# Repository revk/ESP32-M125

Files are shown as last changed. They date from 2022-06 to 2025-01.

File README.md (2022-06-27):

# ESP32-M125

This is hardware and software designed to be fitted within a Marsden M-125 set of medical scales.

Examples of modifications with much older prototype boards https://youtu.be/l1VAymhwtVMand  https://youtu.be/jy-5EB_Qu8Y

M125 09 51 44

Takes data when SEND pressed and reports via MQTT and https. But can also work with an NFC board https://github.com/revk/ESP32-PN532 so tapping a card or tag will report ID and weight, pressing SEND for you.

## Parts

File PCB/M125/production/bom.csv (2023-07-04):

Designator | Footprint | Quantity | Value | LCSC Part #
C1 | C_0402 | 1 | 1uF
C2 | C_0402 | 1 | 100nF
C6 | C_0603_ | 1 | 10uF 50V | C1591
C7 | C_0603_ | 1 | 10uF 6.3V | C1691
C8 | C_0603_ | 1 | 100nF
D3 | LED-RGB-1.6x1.6 | 1 | RGB | C264508
J1, J2 | PTSM-HH-4-RA | 2 | Conn_01x04
J3 | Shelly | 1 | Shelly
L2 | L_4x4_ | 1 | 10uH
Q1 | SOT-323_SC-70 | 1 | PMF250XNEX
R10 | R_0402_ | 1 | 124k
R11 | R_0402_ | 1 | 39k2
R12 | R_0402_ | 1 | 1M
R4 | R_0402 | 1 | 10K
R7 | R_0402 | 1 | 680R
R8 | R_0402 | 1 | 2K
R9 | R_0402 | 1 | 220R
U1 | ESP32-PICO-MINI-02 | 1 | ESP32-PICO-MINI-02
U3 | SOT-23-6-MD8942 | 1 | MD8942 | C2684786

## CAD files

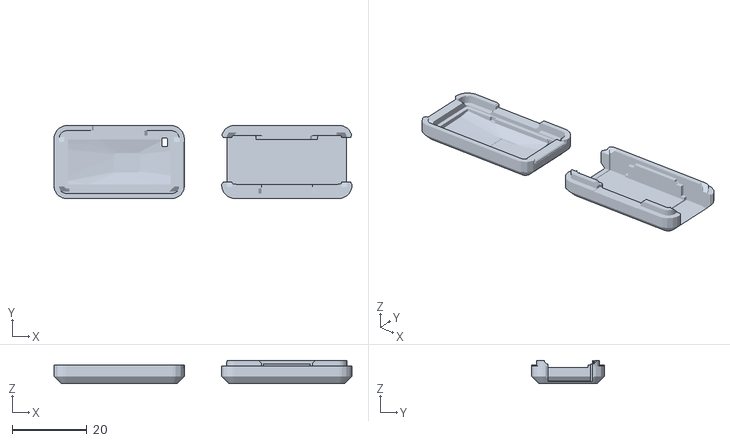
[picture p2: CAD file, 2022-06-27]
PCB/M125/M125.stl
80.0 x 19.6 x 6.30

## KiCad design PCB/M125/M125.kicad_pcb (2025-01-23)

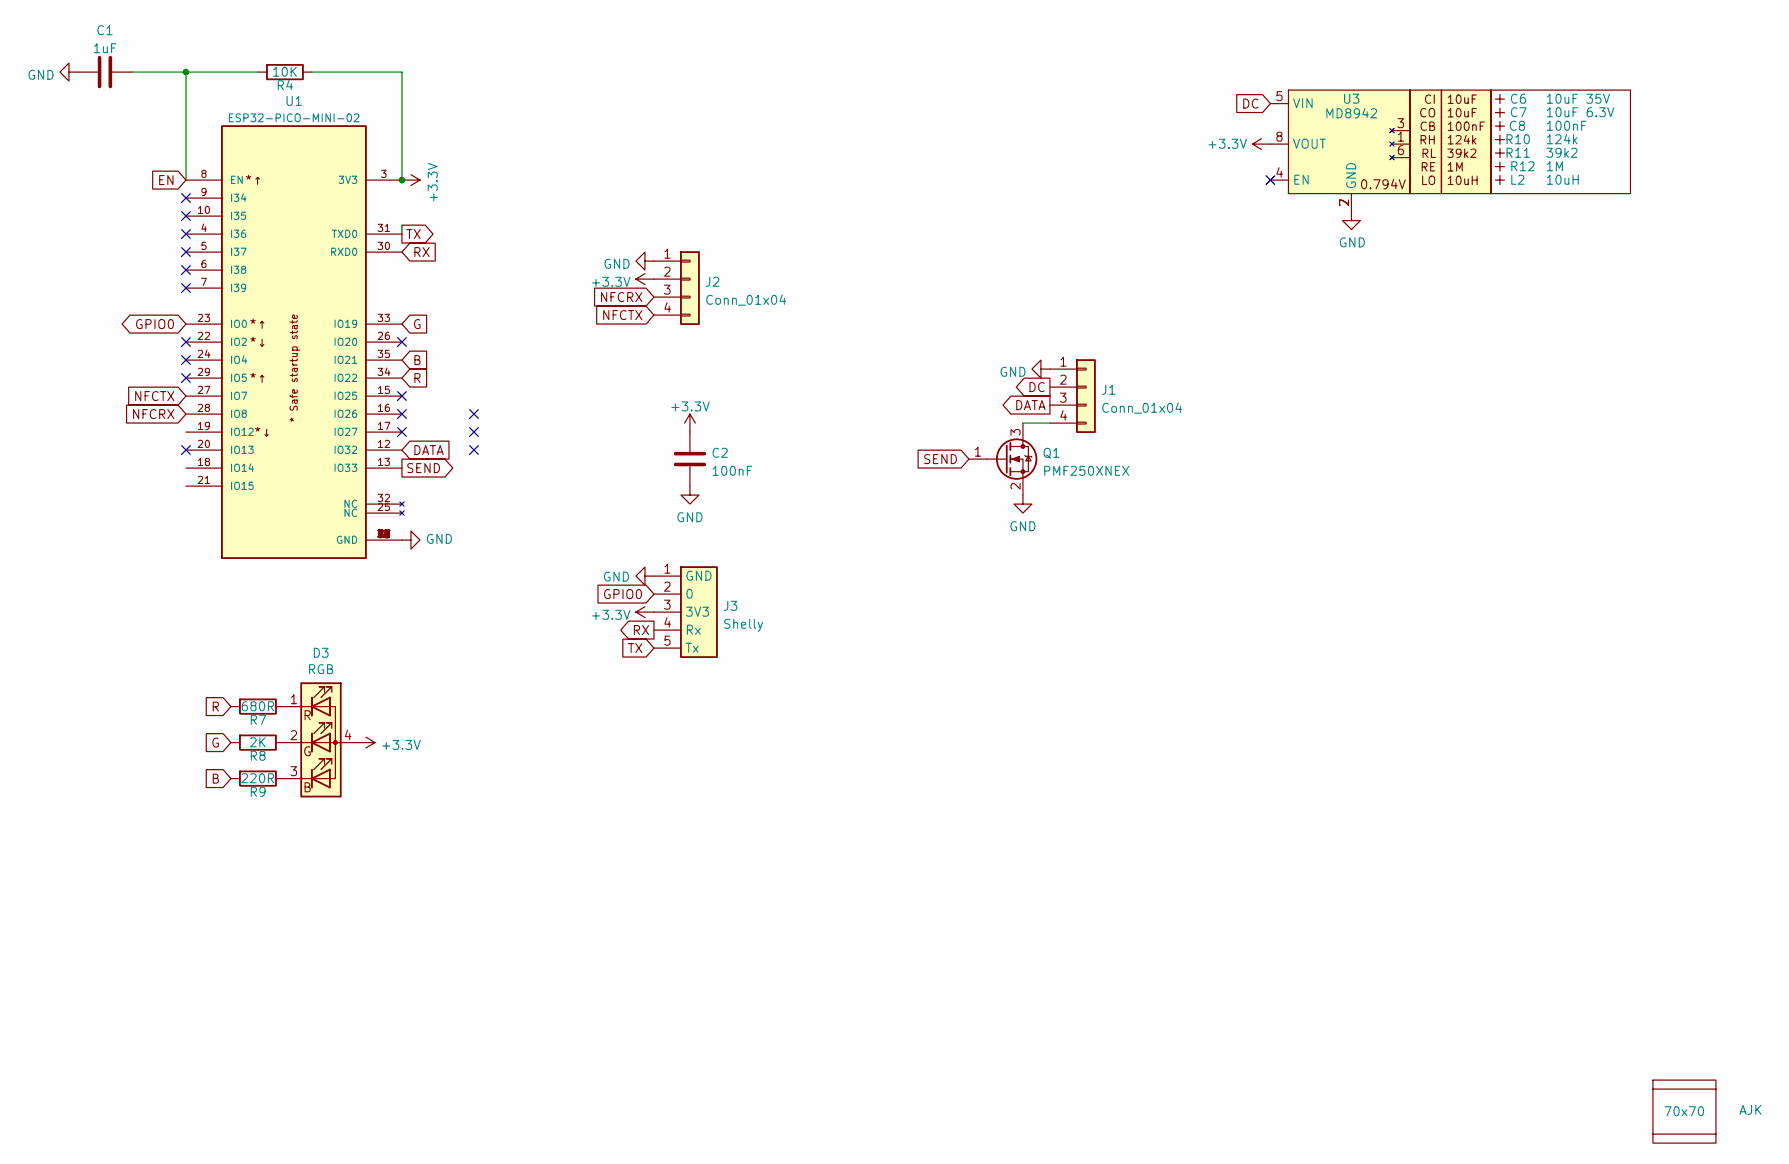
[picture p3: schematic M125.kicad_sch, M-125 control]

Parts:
C1: 1uF; C_0402
C2: 100nF; C_0402
C6: 10uF 35V; C_0603_; MPN C194427
C7: 10uF 6.3V; C_0603_; MPN C1691
C8: 100nF; C_0603_
D3: RGB; LED-RGB-1.6x1.6; Part No APTF1616LSEEZGKQBKC
J1, J2: Conn_01x04; PTSM-HH-4-RA
J3: Shelly
L2: 10uH; L_4x4_
Logo1: AJK
PCB1: 70x70; PCB7070
Q1: PMF250XNEX; SOT-323_SC-70; Part No PMF250XNEX
R4: 10K; R_0402
R7: 680R; R_0402
R8: 2K; R_0402
R9: 220R; R_0402
R10: 124k; R_0402_
R11: 39k2; R_0402_
R12: 1M; R_0402_
U1: ESP32-PICO-MINI-02; PARTREV v1.0
U3: MD8942; SOT-23-6-MD8942; MPN C2684786
V1, V2: VCUT70

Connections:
+3V3: C2.1, D3.4 (A), J2.2, J3.3 (3V3), R4.1, U1.3 (3V3), U3.8 (VOUT)
B: R9.2, U1.35 (IO21)
DATA: J1.3, U1.12 (IO32)
DC: J1.2, U3.5 (VIN)
EN: C1.2, R4.2, U1.8 (EN)
G: R8.2, U1.33 (IO19)
GND: C1.1, C2.2, J1.1, J2.1, J3.1 (GND), Q1.2 (S), U1.1 (GND), U1.2 (GND), U1.11 (GND), U1.14 (GND), U1.36 (GND), U1.37 (GND), U1.38 (GND), U1.39 (GND), U1.40 (GND), U1.41 (GND), U1.42 (GND), U1.43 (GND), U1.44 (GND), U1.45 (GND), U1.46 (GND), U1.47 (GND), U1.48 (GND), U1.49 (GND), U1.50 (GND), U1.51 (GND), U1.52 (GND), U1.53 (GND), U3.2 (GND), U3.7 (GND)
GPIO0: J3.2 (0), U1.23 (IO0)
NFCRX: J2.3, U1.28 (IO8)
NFCTX: J2.4, U1.27 (IO7)
unnamed: D3.3 (BK), R9.1
unnamed: D3.2 (GK), R8.1
unnamed: D3.1 (RK), R7.1
unnamed: J1.4, Q1.3 (D)
R: R7.2, U1.34 (IO22)
RX: J3.4 (Rx), U1.30 (RXD0)
SEND: Q1.1 (G), U1.13 (IO33)
TX: J3.5 (Tx), U1.31 (TXD0)

Board: 2 copper layers, 24 parts (18 on the bottom side), 18 nets, no tracks yet.

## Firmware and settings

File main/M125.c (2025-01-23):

/* M125 app */
/* Copyright ©2022 Adrian Kennard, Andrews & Arnold Ltd.See LICENCE file for details .GPL 3.0 */

static const char __attribute__((unused)) TAG[] = "M125";

#include "revk.h"
#include "esp_sleep.h"
#include "esp_task_wdt.h"
#include "esp_http_client.h"
#include "esp_http_server.h"
#include "esp_crt_bundle.h"
#include "pn532.h"
#include <driver/gpio.h>
#include <driver/uart.h>

#ifdef	CONFIG_LWIP_DHCP_DOES_ARP_CHECK
#warning CONFIG_LWIP_DHCP_DOES_ARP_CHECK means DHCP is slow
#endif
#ifndef	CONFIG_LWIP_DHCP_RESTORE_LAST_IP
#warning CONFIG_LWIP_DHCP_RESTORE_LAST_IP may improve speed
#endif
#ifndef	CONFIG_BOOTLOADER_SKIP_VALIDATE_IN_DEEP_SLEEP
#warning CONFIG_BOOTLOADER_SKIP_VALIDATE_IN_DEEP_SLEEP may speed boot
#endif
#if	CONFIG_BOOTLOADER_LOG_LEVEL > 0
#warning CONFIG_BOOTLOADER_LOG_LEVEL recommended to be no output
#endif

pn532_t *pn532 = NULL;
char fobid[21];
char weight[30];
volatile uint8_t tagready = 0;
volatile uint8_t weightready = 0;

void
uart_task (void *arg)
{
   esp_err_t err = 0;
   uart_config_t uart_config = {
      .baud_rate = 9600,
      .data_bits = UART_DATA_8_BITS,
      .parity = UART_PARITY_DISABLE,
      .stop_bits = UART_STOP_BITS_1,
      .flow_ctrl = UART_HW_FLOWCTRL_DISABLE,
      .source_clk = UART_SCLK_DEFAULT,
   };
   if (!err)
      err = uart_param_config (uart, &uart_config);
   if (!err)
      err = uart_set_pin (uart, -1, rx.num, -1, -1);
   if (!err)
      err = uart_driver_install (uart, 1024, 0, 0, NULL, 0);
   if (err)
   {
      jo_t j = jo_object_alloc ();
      jo_string (j, "error", "Failed to uart");
      jo_int (j, "uart", uart);
      jo_int (j, "gpio", rx.num);
      jo_string (j, "description", esp_err_to_name (err));
      revk_error ("uart", &j);
      return;
   }
   while (1)
   {
      char buf[256];
      int len = 0;
      len = uart_read_bytes (uart, buf, sizeof (buf) - 1, 100 / portTICK_PERIOD_MS);
      if (len <= 0)
         continue;
      buf[len] = 0;
      if (weightready)
         continue;
      // Extract net weight
      char *g = strstr (buf, "NET WEIGHT");
      if (!g)
         continue;
      g += 10;
      while (*g == ' ')
         g++;
      char *e = strchr (g, '\r');
      if (!e || e - g > sizeof (weight))
         continue;
      *e = 0;
      strcpy (weight, g);
      ESP_LOGI (TAG, "Weight:%s", weight);
      weightready = 1;
   }
}

void
reader_task (void *arg)
{
   int cards = 0;
   while (1)
   {
      usleep (100000);
      if (!pn532)
      {
         pn532 = pn532_init (nfcuart, 4, nfctx.num, nfcrx.num, 0);
         if (!pn532)
            continue;
         ESP_LOGI (TAG, "NFC Init OK");
      }
      if (cards)
      {
         if (pn532_Present (pn532))
            continue;
         cards = 0;
         ESP_LOGI (TAG, "Gone");
      }
      if (tagready)
         continue;              // Waiting
      cards = pn532_Cards (pn532);
      if (cards <= 0)
         continue;
      pn532_nfcid (pn532, fobid);
      if (!*fobid)
         continue;
      ESP_LOGI (TAG, "Card %s", fobid);
      tagready = 1;
   }
}

const char *
app_callback (int client, const char *prefix, const char *target, const char *suffix, jo_t j)
{
   char value[1000];
   int len = 0;
   *value = 0;
   if (j)
   {
      len = jo_strncpy (j, value, sizeof (value));
      if (len < 0)
         return "Expecting JSON string";
      if (len > sizeof (value))
         return "Too long";
   }
   if (client || !prefix || target || strcmp (prefix, prefixcommand) || !suffix)
      return NULL;              //Not for us or not a command from main MQTT
   if (!strcmp (suffix, "connect"))
   {
   }
   return NULL;
}

// --------------------------------------------------------------------------------
// Web
#ifdef	CONFIG_REVK_APCONFIG
#error 	Clash with CONFIG_REVK_APCONFIG set
#endif

void
app_main ()
{
   *fobid = 0;
   *weight = 0;
   revk_boot (&app_callback);
   revk_start ();
   if (!*cloudhost || !*cloudpass)
   {                            // Special defaults
      jo_t j = jo_object_alloc ();
      if (!*cloudhost)
         jo_string (j, "cloudhost", "weigh.me.uk");
      if (!*cloudpass)
      {
         int i;
         char pass[33];
         for (i = 0; i < sizeof (pass) - 1; i++)
            pass[i] = 'A' + (esp_random () % 26);
         pass[i] = 0;           // End
         jo_string (j, "cloudpass", pass);
      }
      revk_setting (j);
      jo_free (&j);
   }

   revk_task ("uart", uart_task, 0, 8);
   revk_task ("reader", reader_task, 0, 8);

   revk_gpio_output (button);
   revk_gpio_set (button, 0);

   while (1)
   {                            // Main loop, pick up uart and reader events
      usleep (100000);
      if (tagready)
      {                         // We press button until we get weight or give up
         int try = 20;
         if (!button.set)
            sleep (5);
         else
            while (try-- && !weightready)
            {
               ESP_LOGI (TAG, "Pushing send");
               revk_gpio_set (button, 1);
               usleep (100000);
               revk_gpio_set (button, 0);
               sleep (2);
               if (weightready && *weight == '0')
                  weightready = 0;      // Try again. Small weight
            }
      }
      if (tagready || weightready)
      {                         // Send
         ESP_LOGI (TAG, "Send data");
         float kg = -1;
         jo_t j = jo_object_alloc ();
         if (tagready)
            jo_string (j, "id", fobid);
         if (weightready)
         {
            jo_string (j, "weight", weight);
            // NET WEIGHT    0 st  0.0 lb
            // NET WEIGHT         0.00 kg
            float st,
              lb;
            if (strstr (weight, "st") && sscanf (weight, "%f st %f lb", &st, &lb) == 2)
               kg = (st * 14 + lb) / 2.20462;
            else if (strstr (weight, "lb") && sscanf (weight, "%f lb", &lb) == 1)
               kg = lb / 2.20462;
            else if (strstr (weight, "kg") && sscanf (weight, "%f kg", &lb) == 1)
               kg = lb;
            if (kg >= 0)
               jo_litf (j, "kg", "%.2f", kg);
         }
         revk_error ("weight", &j);

         if (weightready && kg > 0 && (*toot || *topic))
         {
            struct tm t;
            time_t now = time (0);
            localtime_r (&now, &t);
            char when[40];
            strftime (when, sizeof (when), "%a %F %T %Z", &t);

            char *pl = NULL;
            asprintf (&pl, "@%s\nGood %s, your weight is %.2fkg (%s)\r\n%s %s %s\r\n\r\n",      //
                      toot,     //
                      t.tm_hour < 12 ? "morning" : t.tm_hour < 18 ? "afternoon" : "evening", kg, weight,        //
                      when, hostname, fobid);
            if (*toot)
               revk_mqtt_send_raw ("toot", 0, pl, 1);
            if (*topic)
               revk_mqtt_send_raw (topic, 0, pl + 2 + strlen (toot), 1);
            free (pl);
         }
         if (*cloudhost)
         {
            char url[250];
            int m = sizeof (url) - 1,
               p = 0;
            if (p < m)
               p += snprintf (url + p, m - p, "https://%s", cloudhost);
            if (p < m)
               p += snprintf (url + p, m - p, "/weighin.cgi?version=%s", revk_version);
            if (p < m)
               p += snprintf (url + p, m - p, "&scales=%s", revk_id);
            if (p < m && cloudpass)
               p += snprintf (url + p, m - p, "&auth=%s", cloudpass);   // Assume no special characters
            if (p < m && weightready)
               p += snprintf (url + p, m - p, "&weight=%s", weight);
            if (p < m && weightready && kg >= 0)
               p += snprintf (url + p, m - p, "&kg=%.2f", kg);
            if (p < m && tagready)
               p += snprintf (url + p, m - p, "&id=%s", fobid);
            url[p] = 0;
            for (p = 0; url[p]; p++)
               if (url[p] == ' ')
                  url[p] = '+';
            esp_http_client_config_t config = {.url = url,.crt_bundle_attach = esp_crt_bundle_attach };
            esp_http_client_handle_t client = esp_http_client_init (&config);
            if (client)
            {
               esp_http_client_perform (client);
               esp_http_client_flush_response (client, NULL);
               int status = esp_http_client_get_status_code (client);
               if (status == 426)
                  revk_command ("upgrade", NULL);       // Upgrade requested by server
               esp_http_client_cleanup (client);
            }
         }
         *fobid = 0;
         *weight = 0;
         tagready = 0;
         weightready = 0;
      }
   }
}

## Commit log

2022-06-25 Tweak PCBs
    [M125.kicad_pcb, M125.kicad_sch]
2022-06-27 New PCB
    [M125-B_Cu.gbr, M125-B_Mask.gbr, M125-B_Paste.gbr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]
2022-06-28 Tidy PCB for placement of regulator parts
    [M125-B_Cu.gbr, M125-B_Mask.gbr, M125-B_Paste.gbr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]
2023-07-04 Library update
    [M125.kicad_pcb, M125.kicad_sch, bom.csv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]
2025-01-23 PCB Update
    [M125.kicad_pcb, M125.kicad_sch]
